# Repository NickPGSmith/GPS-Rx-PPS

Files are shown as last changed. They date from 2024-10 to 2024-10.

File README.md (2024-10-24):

# GPS-Rx-PPS
A KiCAD schematic and PCB to buffer/alarm a GPS receiver PPS signal

## Introduction

There are many cheap GPS receiver boards available which provide a serial output and Pulse-Per-Second (PPS) output, typically based on the uBlox 6 or later chip. This board is designed to take the PPS signal from such a receiver and provide buffering, LED drive, and missing pulse alarm (audio and LED).

For a printable schematic, see the file:
- GPS Rx PPS_sch.pdf

For a file to send to a fabricator (eg JLCPCB or PCBWay), use the file:
- Fabrication/GPS Rx PPS.zip

## uBlox Receiver Configuration

The uBlox receiver can be configured via the serial line using the [uCenter](https://www.u-blox.com/en/product/u-center) software. It should generate a 1 Hz outout (timed on falling edge) when GPS synchronisation has been obtained, otherwise a constant high to indicate failure:

View -> Configuration View; to activate change: Send

- TP5 (Timepulse 5)
    - PPS Settings for no GPS lock (use as an "alert" signal:
        - Frequency : 1 Hz
        - Duty Cycle : 0%
    - PPS Settings for GPS Locked:
        - Frequency Locked : 1 Hz
        - Duty Locked : 50%
    - Falling Edge on TOS

To save:
- CFG (Configuration)
    - Select: Save current configuration
    - Select in Devices: 2-I2C-EEPROM

## Circuit Description

The GPS receiver PPS signal is buffered by U2B to provide LED output, U2C to provide buffer drive for an external circuit, and the missing pulse detector built around U1. This will generate a low output after a few seconds of not receiving pulses; the timing can be adjusted by the combination of R3 and C4.

U2D and U2E provide an audio oscillator of a few kHz; its frequency can be adjusted by R9 and C6 to match the resonant frequncy of the piezo sounder used. The oscillator uses U2F as an output buffer/drive, with RV1 preset setting the desired volume.
The oscillations are quenched when Q2 is turned on, ie when the "Not Alarm" output of U1 is high.

PCB Connections:
- CON1: DC Power in (5 V)
- CON2: Power LED
- CON3: Alarm LED
- CON4: PPS in, from GPS received (timing on falling edge)
- CON5: PPS LED
- CON6: PPS out (jumper selects low impendance or 50 Ohm)
- CON7: Alarm sounder out

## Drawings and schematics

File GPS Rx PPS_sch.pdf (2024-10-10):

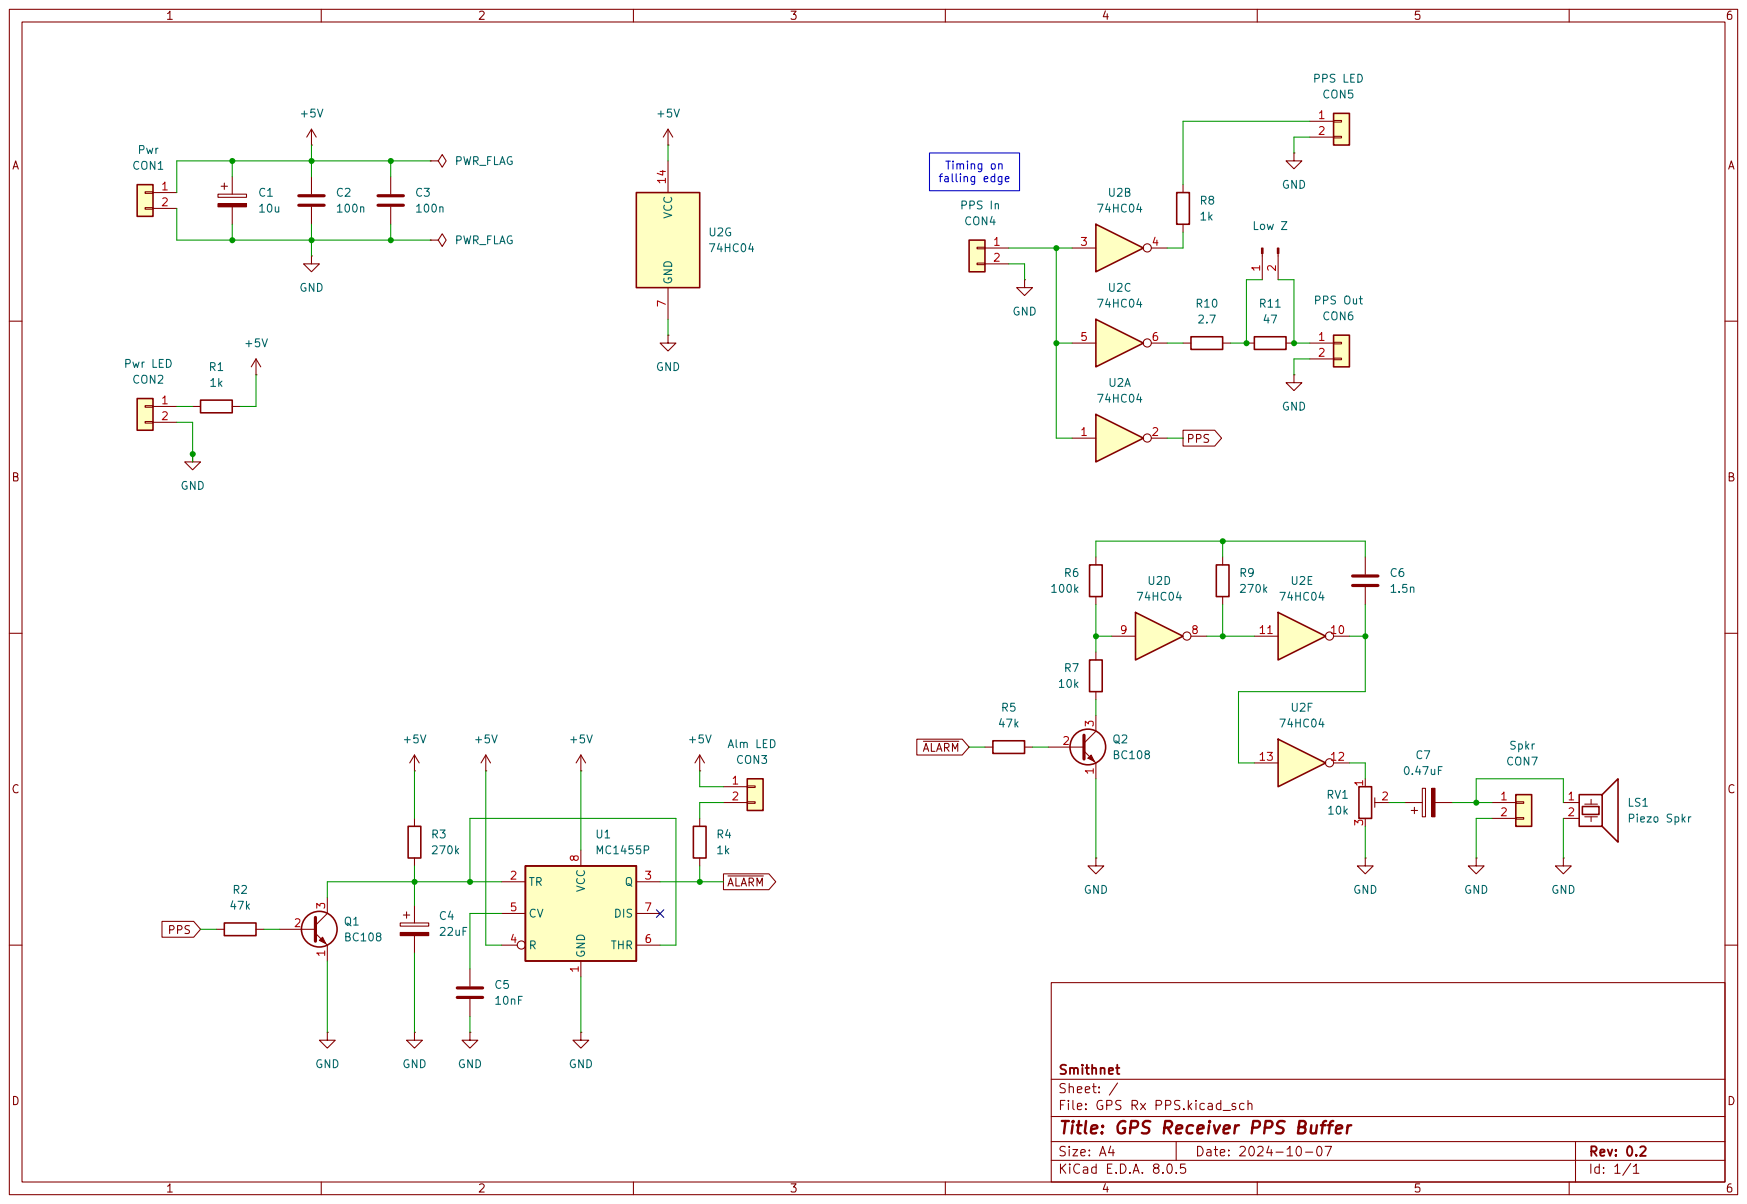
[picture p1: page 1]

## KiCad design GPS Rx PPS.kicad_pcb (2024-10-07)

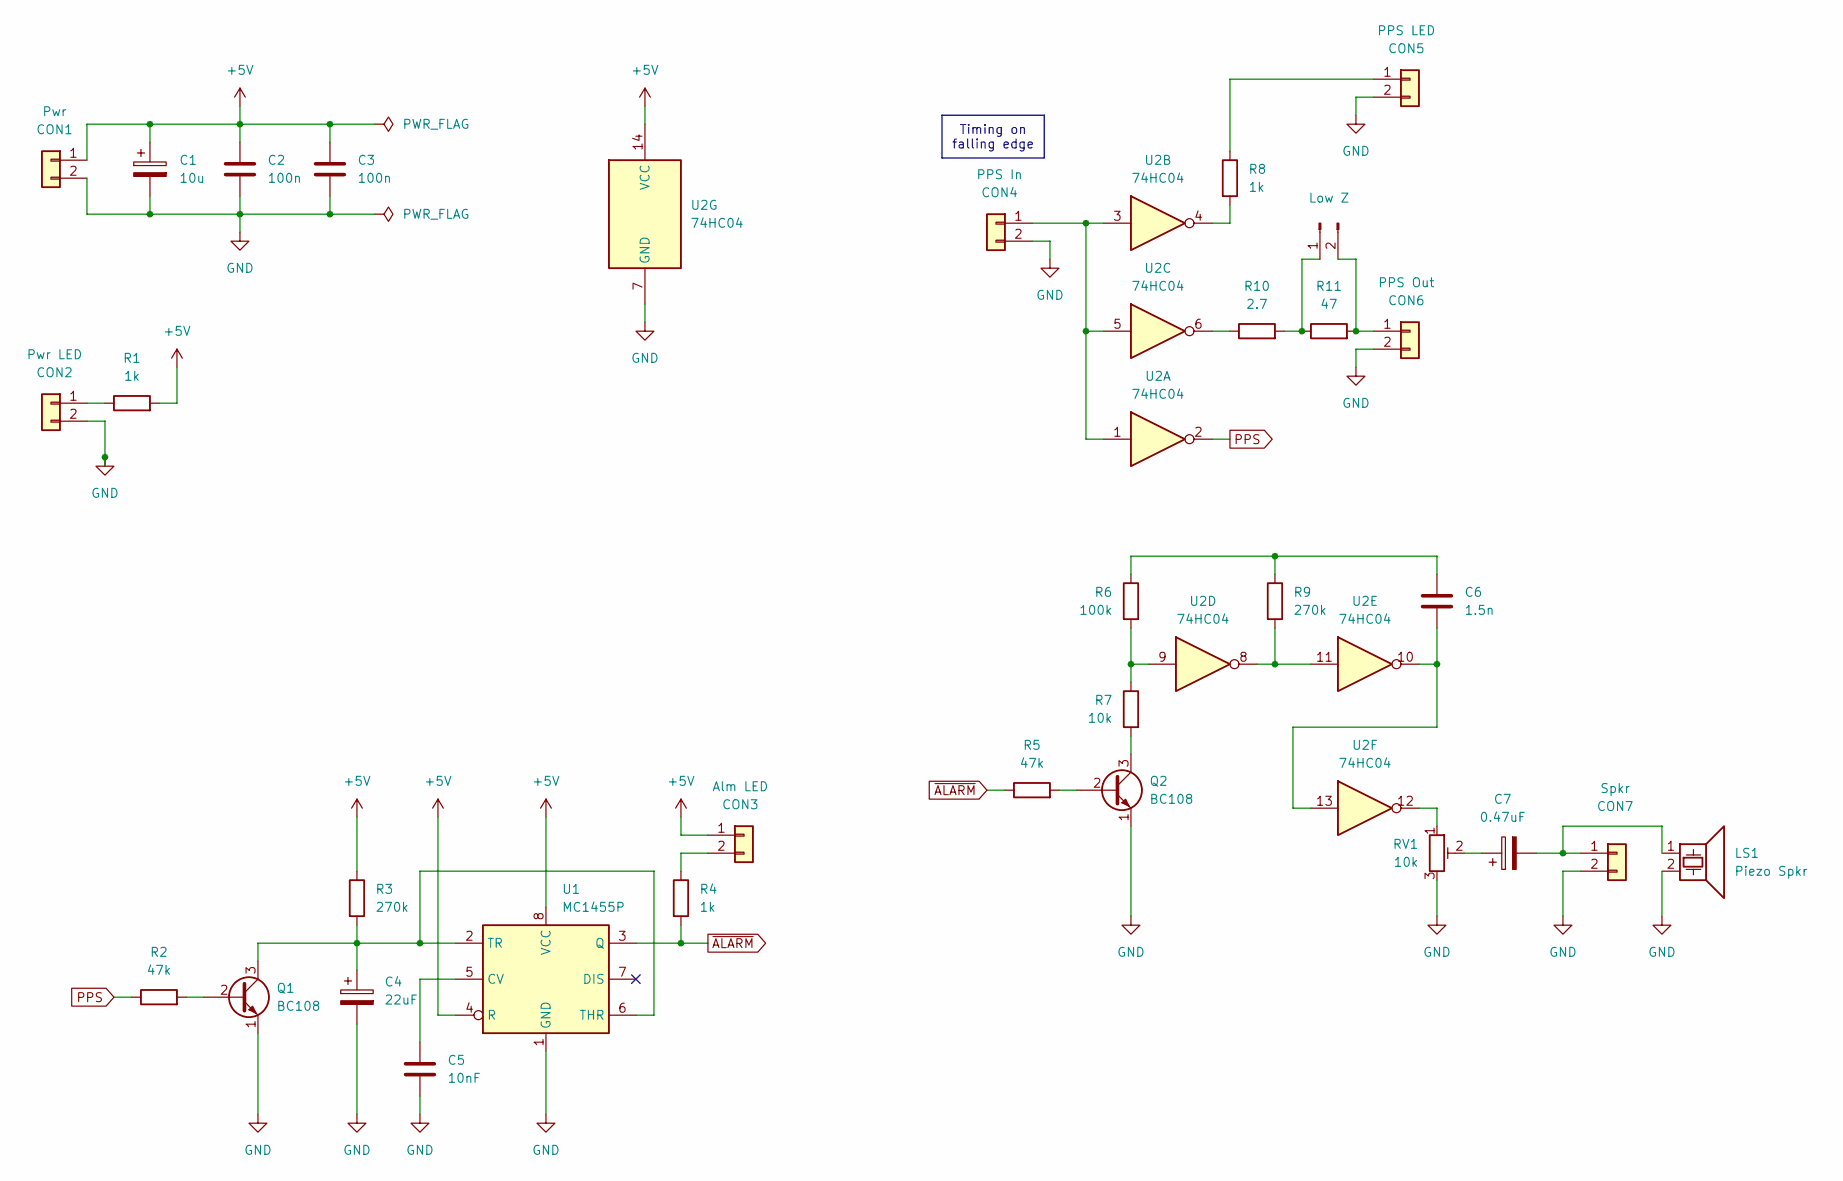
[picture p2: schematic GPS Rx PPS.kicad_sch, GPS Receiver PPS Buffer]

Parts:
C1: 10u; CP_Radial_D5.0mm_P2.00mm
C2, C3: 100n; C_Disc_D3.0mm_W1.6mm_P2.50mm
C4: 22uF; CP_Radial_D5.0mm_P2.00mm
C5: 10nF; C_Disc_D4.3mm_W1.9mm_P5.00mm
C6: 1.5n; C_Disc_D3.0mm_W1.6mm_P2.50mm
C7: 0.47uF; CP_Radial_D6.3mm_P2.50mm
CON1: Pwr; PinHeader_1x02_P2.54mm_Vertical
CON2: Pwr LED; PinHeader_1x02_P2.54mm_Vertical
CON3: Alm LED; PinHeader_1x02_P2.54mm_Vertical
CON4: PPS In; PinHeader_1x02_P2.54mm_Vertical
CON5: PPS LED; PinHeader_1x02_P2.54mm_Vertical
CON6: PPS Out; PinHeader_1x02_P2.54mm_Vertical
CON7: Spkr; PinHeader_1x02_P2.54mm_Vertical
J1: Low Z; PinHeader_1x02_P2.54mm_Vertical
LS1: Piezo Spkr; Buzzer_TDK_PS1240P02BT_D12.2mm_H6.5mm
Q1, Q2: BC108; TO-18-3
R1, R4, R8: 1k; R_Axial_DIN0207_L6.3mm_D2.5mm_P2.54mm_Vertical
R2, R5: 47k; R_Axial_DIN0207_L6.3mm_D2.5mm_P2.54mm_Vertical
R3, R9: 270k; R_Axial_DIN0207_L6.3mm_D2.5mm_P2.54mm_Vertical
R6: 100k; R_Axial_DIN0207_L6.3mm_D2.5mm_P2.54mm_Vertical
R7: 10k; R_Axial_DIN0207_L6.3mm_D2.5mm_P2.54mm_Vertical
R10: 2.7; R_Axial_DIN0207_L6.3mm_D2.5mm_P2.54mm_Vertical
R11: 47; R_Axial_DIN0207_L6.3mm_D2.5mm_P2.54mm_Vertical
RV1: 10k; Potentiometer_Piher_PT-6-V_Vertical
U1: MC1455P; DIP-8_W7.62mm_LongPads
U2: 74HC04; CERDIP-14_W7.62mm_SideBrazed_LongPads

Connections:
+5V: C1.1, C2.1, C3.1, CON1.1, CON3.1, R1.2, R3.1, U1.4 (R), U1.8 (VCC), U2.14 (VCC)
GND: C1.2, C2.2, C3.2, C4.2, C5.2, CON1.2, CON2.2, CON4.2, CON5.2, CON6.2, CON7.2, LS1.2, Q1.1 (E), Q2.1 (E), RV1.3, U1.1 (GND), U2.7 (GND)
unnamed: C6.1, R6.1, R9.1
unnamed: C6.2, U2.10, U2.13
unnamed: C7.1, RV1.2
unnamed: CON2.1, R1.1
unnamed: CON3.2, R4.1
unnamed: CON4.1, U2.1, U2.3, U2.5
unnamed: CON5.1, R8.1
unnamed: CON6.1, J1.2, R11.2
unnamed: C7.2, CON7.1, LS1.1
unnamed: J1.1, R10.2, R11.1
unnamed: Q1.2 (B), R2.2
unnamed: C4.1, Q1.3 (C), R3.2, U1.2 (TR), U1.6 (THR)
unnamed: Q2.2 (B), R5.2
unnamed: Q2.3 (C), R7.2
unnamed: R6.2, R7.1, U2.9
unnamed: R8.2, U2.4
unnamed: R9.2, U2.8, U2.11
unnamed: R10.1, U2.6
unnamed: RV1.1, U2.12
unnamed: C5.1, U1.5 (CV)
PPS: R2.1, U2.2
~ALARM: R4.2, R5.1, U1.3 (Q)

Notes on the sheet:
Timing on falling edge

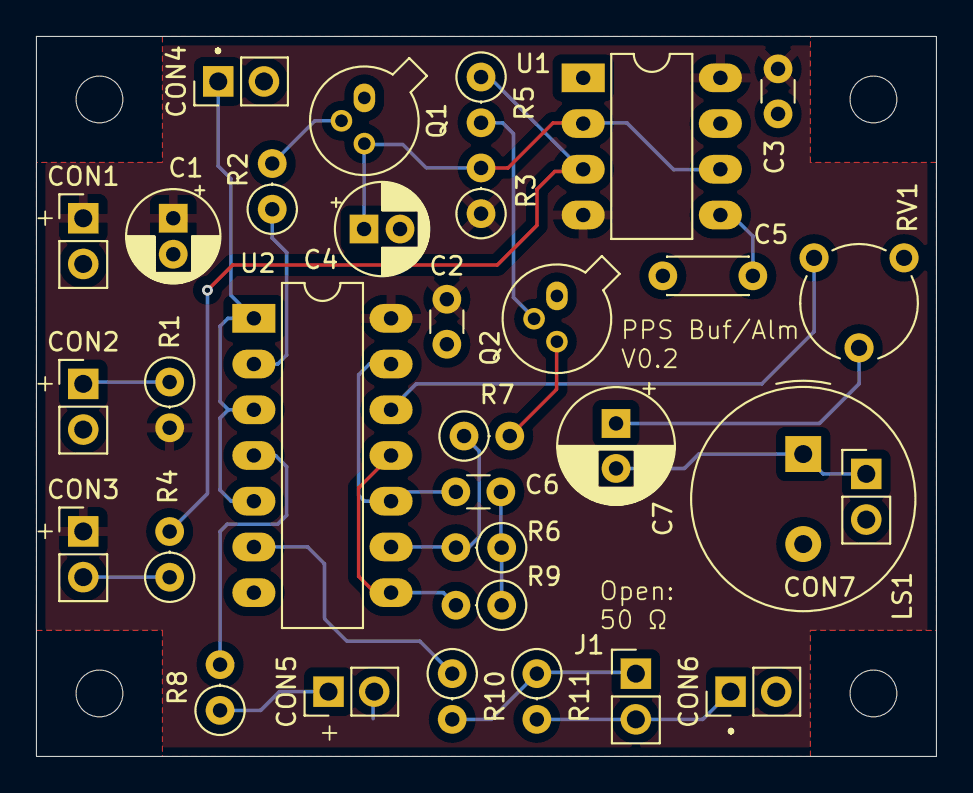
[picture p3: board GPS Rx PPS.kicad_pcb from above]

Board: 2 copper layers, 50.0 x 40.0 mm, 32 parts (0 on the bottom side), 24 nets.
